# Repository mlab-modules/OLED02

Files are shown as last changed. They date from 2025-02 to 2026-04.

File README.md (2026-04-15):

# OLED02 Display with I2C interface

The **OLED02A** is a simplified variant of the MLAB [OLED01](https://github.com/mlab-modules/OLED01) module. It features a 1.3-inch blue OLED display using the SSD1306BZ controller and communicates over an I²C interface.

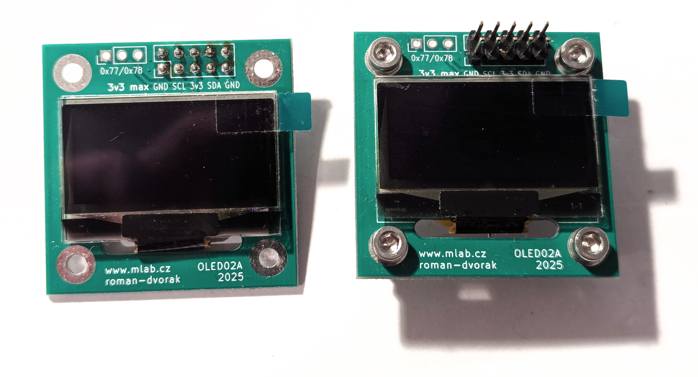
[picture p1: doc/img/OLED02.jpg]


## Features
- **Display**: 1.3-inch passive matrix OLED with a resolution of 128x64 pixels.
- **Color**: Blue.
- **Controller**: SSD1306BZ.
- **Interface**: I²C.
- **Power Supply**:
  - Logic: 3.0 V typical (2.8 V min, 3.3 V max).
  - Display: Internally generated by integrated DC/DC converter.
- **Address Configuration**: Default I²C address is `0x3C`, changeable to `0x3D` via onboard jumper.
- **Mounting**:
  - Horizontal MLAB standard.
  - Optional vertical placement using a 3D-printed holder.

## Electrical Characteristics

- **Operating Voltage (Logic)**: 2.8 V to 3.3 V
- **Operating Current**: \~10 mA @ 12 V VCC (internally generated)
- **Interface Voltage Levels**: TTL-compatible (0 to 3.3 V)

## Optical Characteristics

- **Contrast Ratio**: 2000:1
- **Brightness**: 60–80 cd/m² (typical with 50% checkboard)
- **Viewing Angle**: 160° (H and V)
- **Response Time**: 10 µs (rise and fall)
- **Display Technology**: Passive matrix
- **Pixel Size**: 0.148 mm x 0.148 mm
- **Dot Pitch**: 0.17 mm x 0.17 mm
- **Active Area**: 21.738 mm x 10.858 mm

## Mechanical Parameters

- **Board Dimensions**: 40.14 mm x 40.14 mm
- **Board Thickness**: 1.6 mm
- **Mounting**: Compatible with standard MLAB module placement

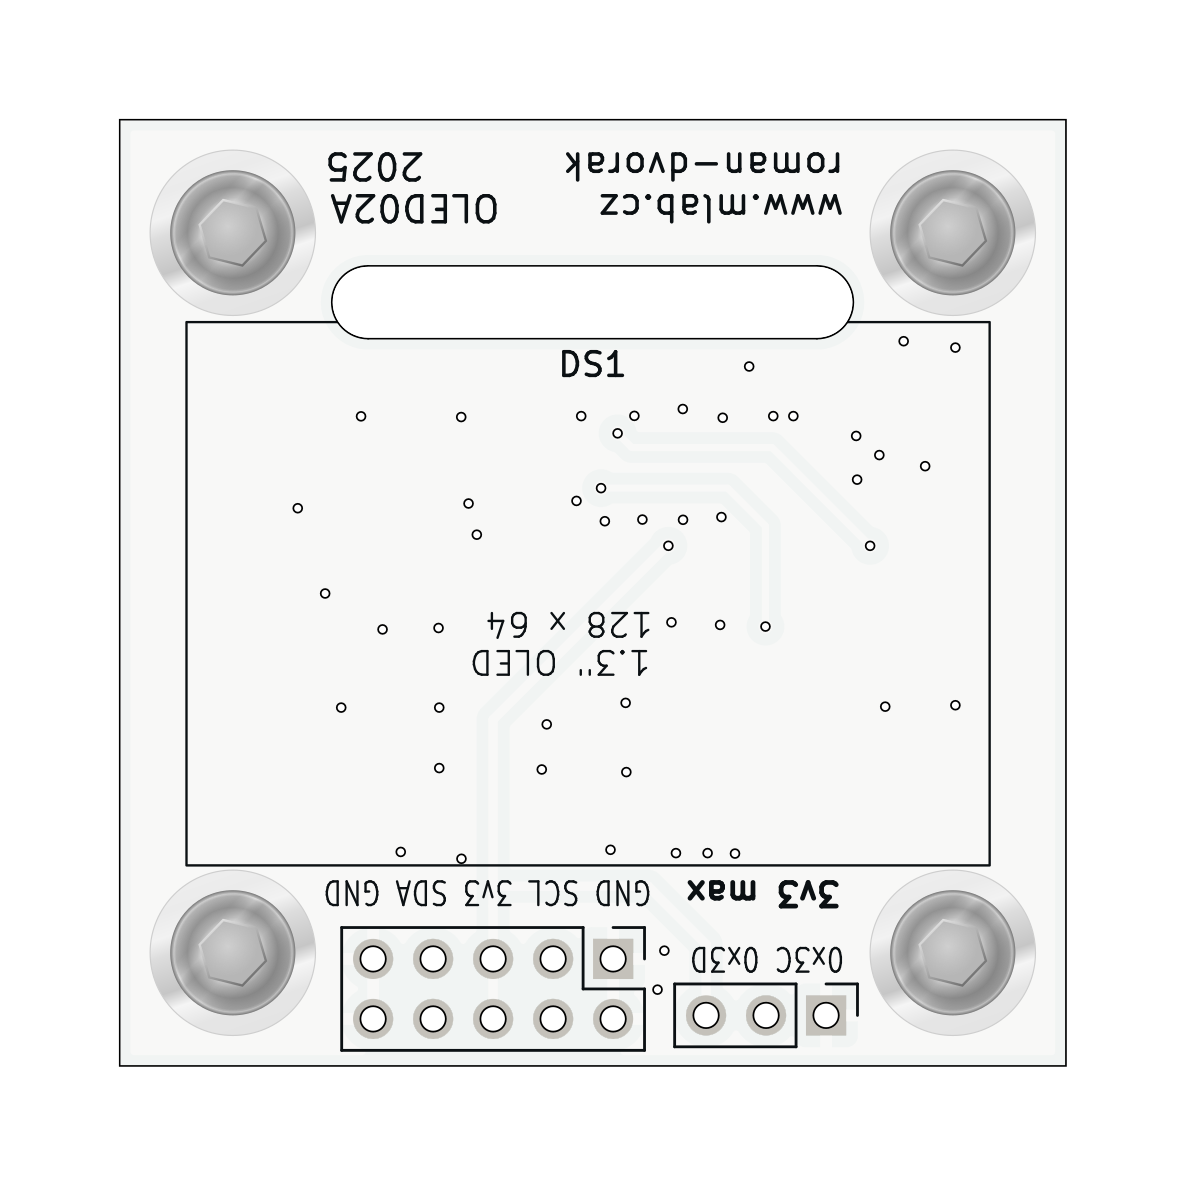
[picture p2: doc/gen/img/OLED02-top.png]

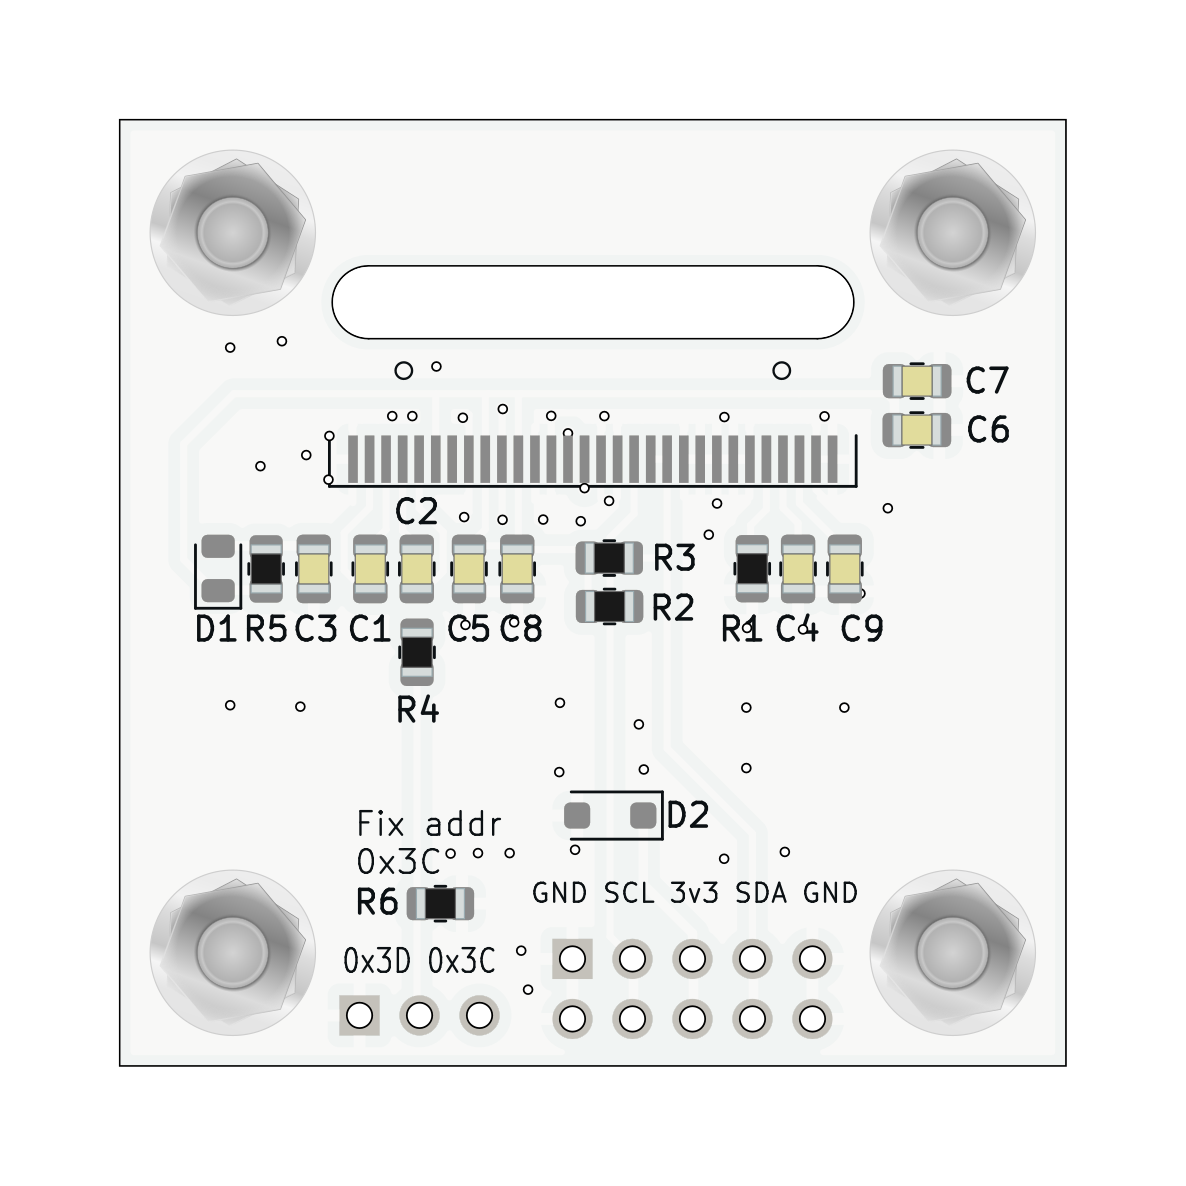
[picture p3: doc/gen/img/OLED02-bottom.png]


## I²C Pin Configuration (Standard MLAB I2C Layout)

| Pin | Name | Description |
| --- | ---- | --- |
| 1 | GND  | Ground |
| 2 | SDA  | Serial Data |
| 3 | 3V3  | 3.3V power supply |
| 4 | SCL  | Serial Clock |
| 5 | GND  | Ground |

## I²C Address Selection

The OLED02A module uses `0x3C` as its default I²C address. By bridging the onboard address jumper, the address switches to `0x3D`.

## Notes

- OLED02A omits certain advanced features present in OLED01 to simplify integration and reduce cost.
- The module uses only the I²C interface; SPI and parallel interfaces supported by the SSD1306BZ are not routed.
- Ensure proper handling precautions for OLEDs to prevent damage or screen burn-in.
- Refer to the [SSD1306 datasheet](https://www.vishay.com/doc?37902) for command interface details.

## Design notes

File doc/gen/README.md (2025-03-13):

# PCB

Board size: 40.14x40.14 mm (1.58x1.58 inches)

- This is the size of the rectangle that contains the board
- Thickness: 1.6 mm (63 mils)
- Material: FR4
- Finish: HAL
- Layers: 2
- Copper thickness: 35 µm

Solder mask: TOP / BOTTOM

- Color: Green

Silk screen: TOP / BOTTOM

- Color: White

# Important sizes

Clearance: 0.2 mm (8 mils)

Track width: 0.3 mm (12 mils)

- By design rules: 0.0 mm (0 mils)

Drill: 0.4 mm (16 mils)

- Vias: 0.4 mm (16 mils) [Design: 0.4 mm (16 mils)]
- Pads: 1.1 mm (43 mils)
- The above values are real drill sizes, they add 0.1 mm (4 mils) to plated holes (PTH)

Via: 0.6/0.3 mm (24/12 mils)

- By design rules: 0.5/0.3 mm (20/12 mils)
- Micro via: yes [0.2/0.1 mm (8/4 mils)]
- Buried/blind via: yes
- Total: 50 (thru: 50 buried/blind: 0 micro: 0)

Outer Annular Ring: 0.1 mm (4 mils)

- By design rules: 0.3 mm (12 mils)

Eurocircuits class: 6C
- Using min drill 0.35 mm for an OAR of 0.13 mm

# General stats

Components count: (SMD/THT)

- Top: 0/6 (THT)
- Bottom: 18/0 (SMD)

Defined tracks:

- 0.2 mm (8 mils)
- 0.3 mm (12 mils)
- 0.4 mm (16 mils)

Used tracks:

- 0.3 mm (12 mils) (94) defined: yes
- 0.4 mm (16 mils) (21) defined: yes

Defined vias:

Used vias:

- 0.6/0.3 mm (24/12 mils) (Count: 50, Aspect: 2.7 A) defined: no

Holes (excluding vias):

- 1.0 mm (39 mils) (13)
- 3.0 mm (118 mils) (4)

Oval holes:

Drill tools (including vias and computing adjusts and rounding):

- 0.4 mm (16 mils) (50)
- 1.1 mm (43 mils) (13)
- 3.1 mm (122 mils) (4)

Solder paste stats:

Using a paste with 87.75 % alloy, that has an specific gravity for the alloy of 7.4 g/cm³
and 1.0 g/cm³ for the flux. This paste has an specific gravity of  4.15 g/cm³.

The stencil thickness is  0.12 mm.

| Side | Pads with paste | Area [mm²] | Paste [g] |
|---|---|---|---|
| Total  | 64 | 70.48 | 0.35 |

Note: this is just an approximation to the theoretical value. Margins of the solder mask and waste aren't computed.

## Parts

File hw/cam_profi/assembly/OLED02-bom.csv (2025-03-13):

Component | Description | Part | References | Value | Footprint | Quantity Per PCB | Datasheet | sim.device | sim.pins | ust_id
1 | Unpolarized capacitor, small symbol | C_Small | C5C6 | 100n | C_0805_2012Metric | 2 | ~
2 | Unpolarized capacitor, small symbol | C_Small | C1C2 | 1u | C_0805_2012Metric | 2 | ~
3 | Unpolarized capacitor, small symbol | C_Small | C4C9 | 4u7 | C_0805_2012Metric | 2 | ~
4 | Unpolarized capacitor, small symbol | C_Small | C3C7C8 | 10u | C_0805_2012Metric | 3 | ~
5 | Diode, small symbol | D_Small | D1 | 1N4148 | D_0805_2012Metric | 1 | ~ | D | 1=K 2=A
6 | Zener diode | D_Zener | D2 | BZT52H-C3V6,115 | D_SOD-123F | 1 | ~ |  |  | 650b35ab462c6d9e720543d0
7 | OLED display 128x64 | OLED-128O064D | DS1 | OLED-128O064D | OLED-128O064D | 1 | https://www.vishay.com/docs/37902/oled128o064dbpp3n00000.pdf
8 | 2x05 2.54 mm pitch header, 2 pins next to each other are connected | HEADER_2x05_PARALLEL | J2 | HEADER_2x05_PARALLEL | PinHeader_2x05_P2.54mm_Vertical | 1
9 | Resistor, small symbol | R_Small | R4 | 100R | R_0805_2012Metric | 1 | ~
10 | Resistor, small symbol | R_Small | R2R3R5R6 | 4k7 | R_0805_2012Metric | 4 | ~
11 | Resistor, small symbol | R_Small | R1 | 560k | R_0805_2012Metric | 1 | ~

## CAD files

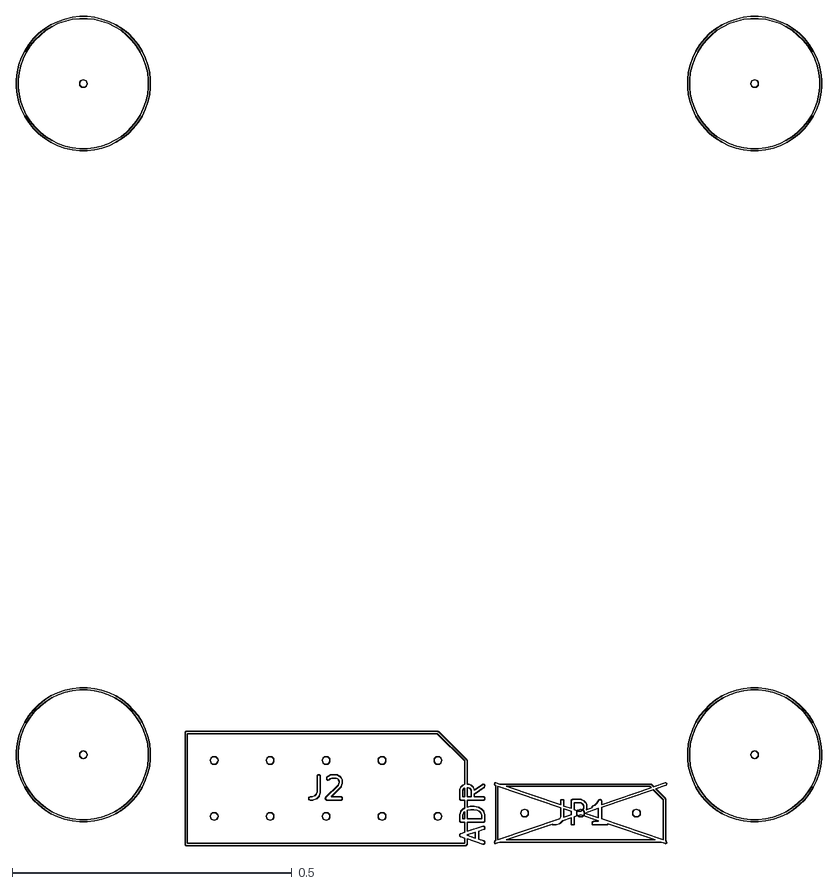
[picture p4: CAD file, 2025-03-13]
doc/gen/dxf/OLED02-F_Fab.dxf
1.44 x 1.48

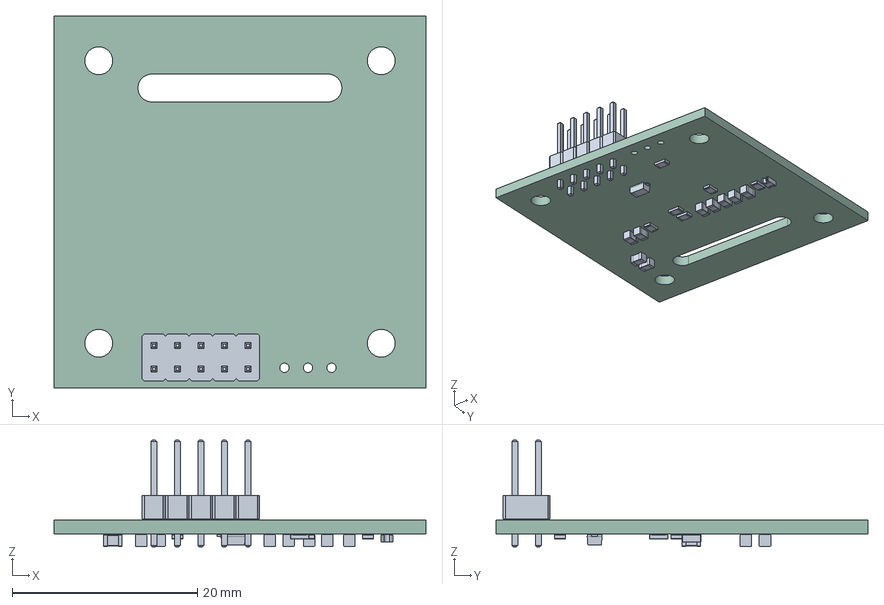
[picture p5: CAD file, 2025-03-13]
doc/gen/OLED02.step
40.1 x 40.1 x 11.5 mm
PinHeader_2x05_P2.54mm_Vertical
D_0805_2012Metric
C_0805_2012Metric x 9
R_0805_2012Metric x 6
D_SOD-123F
kibot_b_ytgxez_PCB

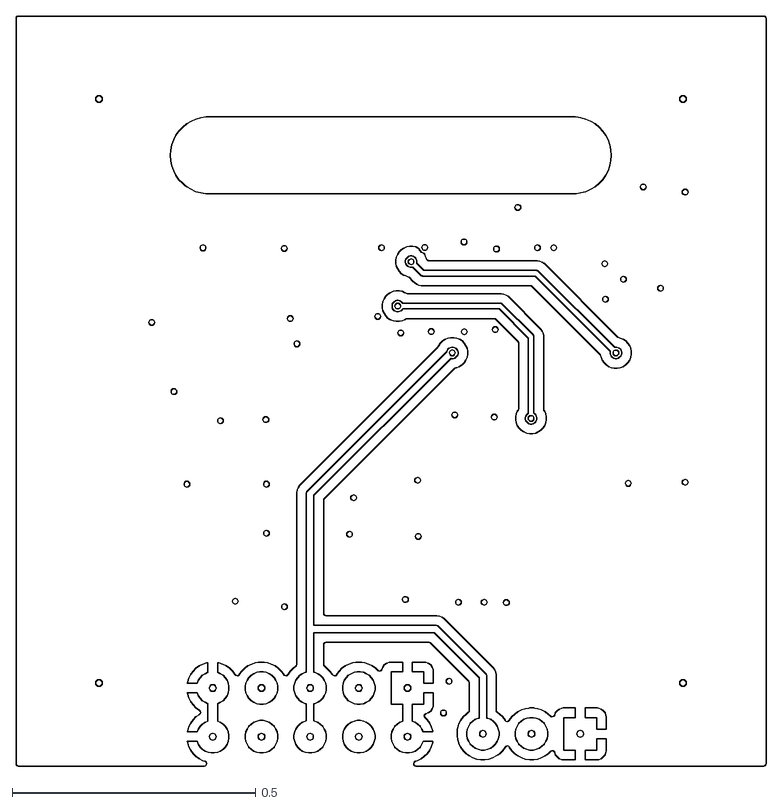
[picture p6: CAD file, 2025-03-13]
doc/gen/dxf/OLED02-F_Cu.dxf
1.54 x 1.54

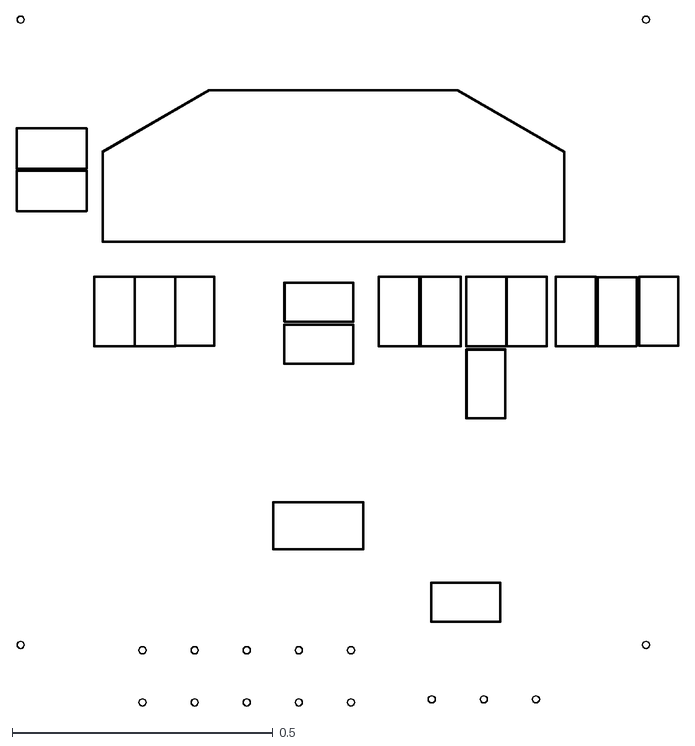
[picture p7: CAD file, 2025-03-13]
doc/gen/dxf/OLED02-B_Courtyard.dxf
1.27 x 1.32

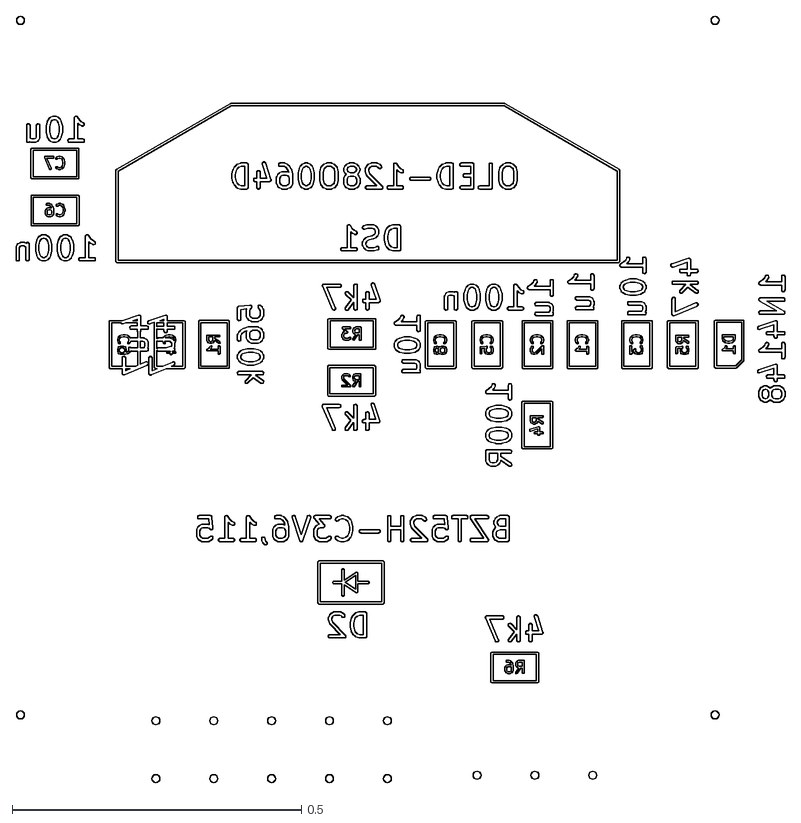
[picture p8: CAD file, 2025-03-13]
doc/gen/dxf/OLED02-B_Fab.dxf
1.33 x 1.32

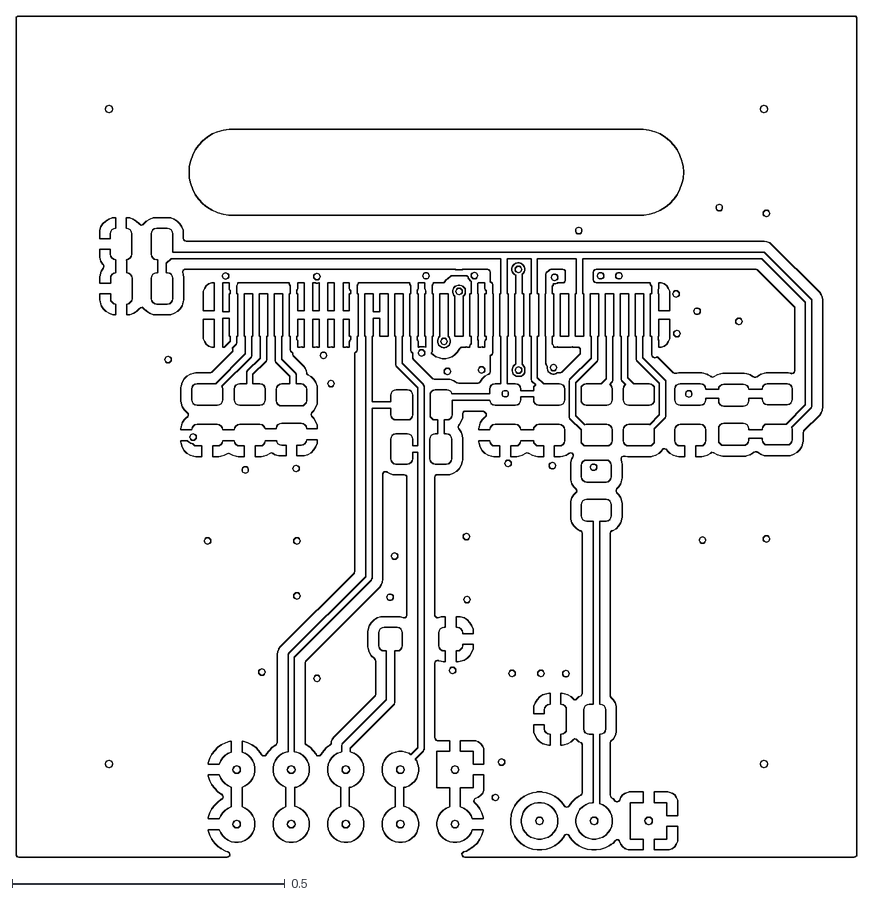
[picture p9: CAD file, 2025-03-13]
doc/gen/dxf/OLED02-B_Cu.dxf
1.54 x 1.54

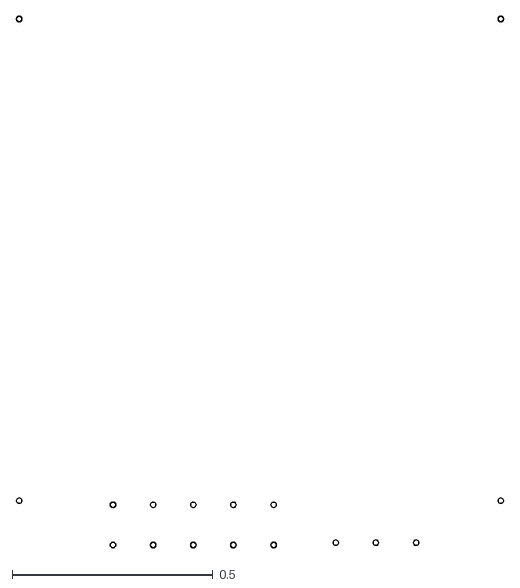
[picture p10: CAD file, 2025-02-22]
doc/gen/dxf/OLED02-User_3.dxf
1.21 x 1.32

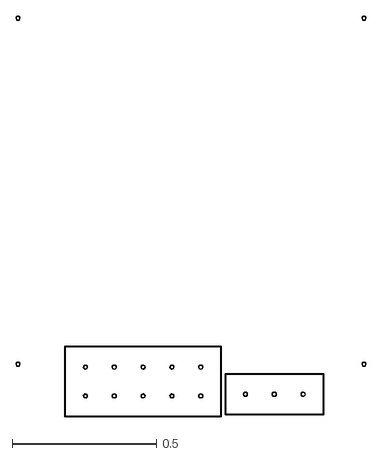
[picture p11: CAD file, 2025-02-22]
doc/gen/dxf/OLED02-F_Courtyard.dxf
1.21 x 1.39

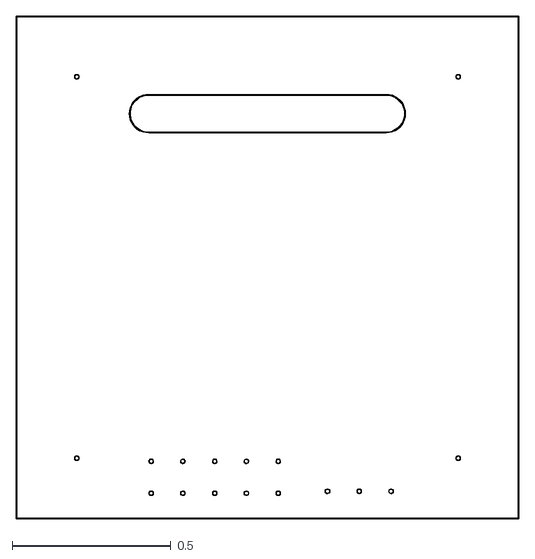
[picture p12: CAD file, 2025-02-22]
doc/gen/dxf/OLED02-Edge_Cuts.dxf
1.58 x 1.58

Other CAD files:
doc/gen/dxf/OLED02-B_Adhesive.dxf
doc/gen/dxf/OLED02-B_Mask.dxf
doc/gen/dxf/OLED02-B_Paste.dxf
doc/gen/dxf/OLED02-B_Silkscreen.dxf
doc/gen/dxf/OLED02-F_Adhesive.dxf
doc/gen/dxf/OLED02-F_Mask.dxf
doc/gen/dxf/OLED02-F_Paste.dxf
doc/gen/dxf/OLED02-F_Silkscreen.dxf

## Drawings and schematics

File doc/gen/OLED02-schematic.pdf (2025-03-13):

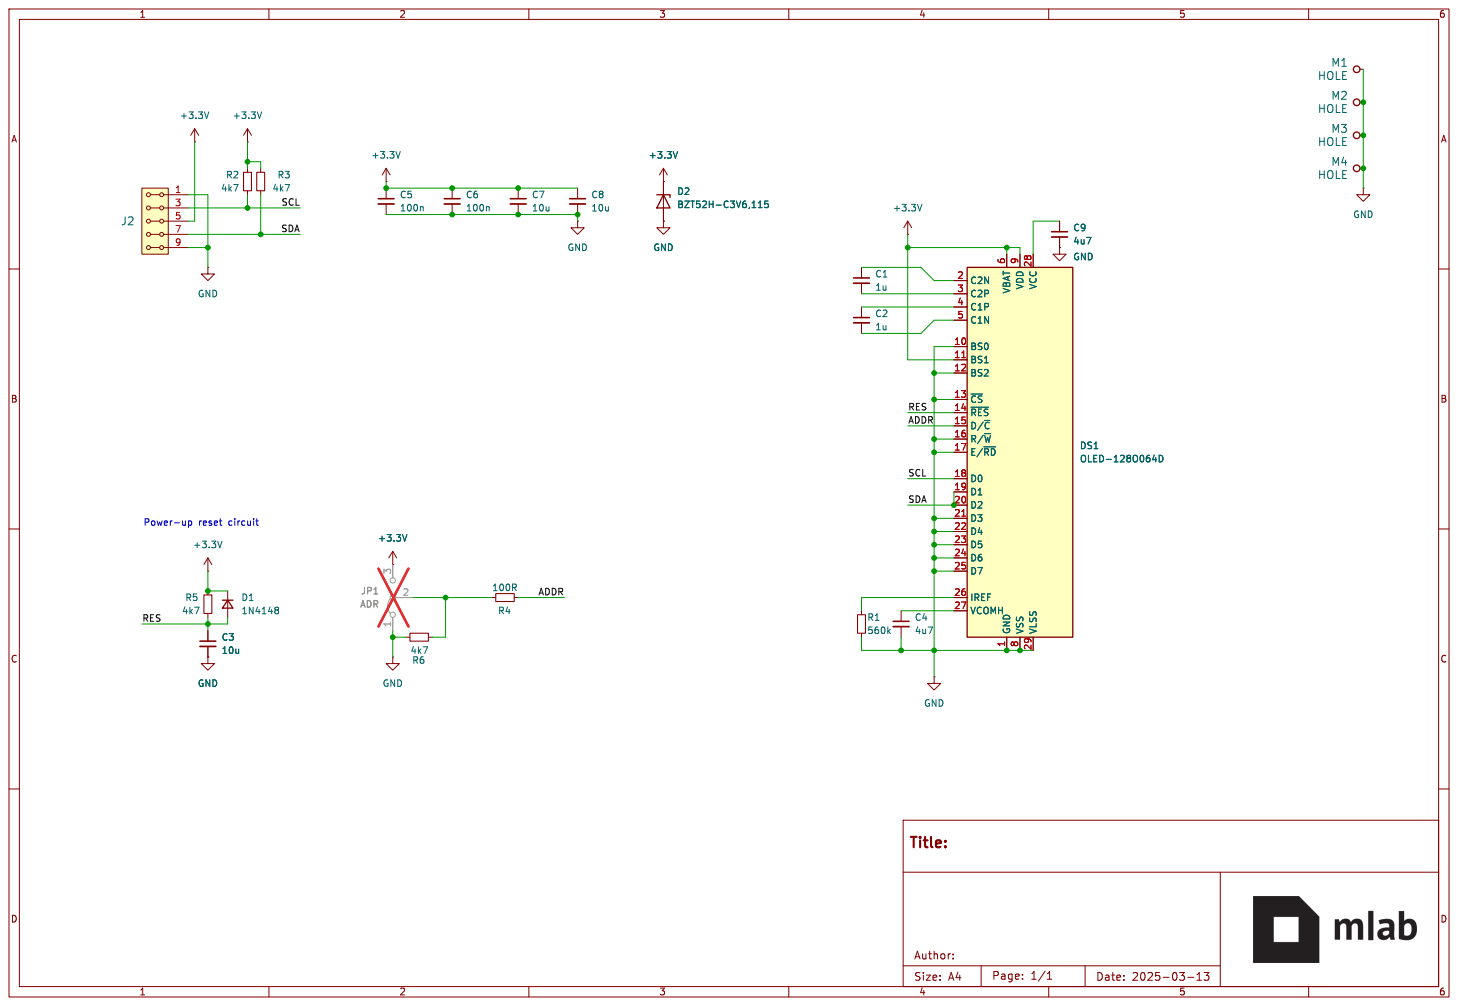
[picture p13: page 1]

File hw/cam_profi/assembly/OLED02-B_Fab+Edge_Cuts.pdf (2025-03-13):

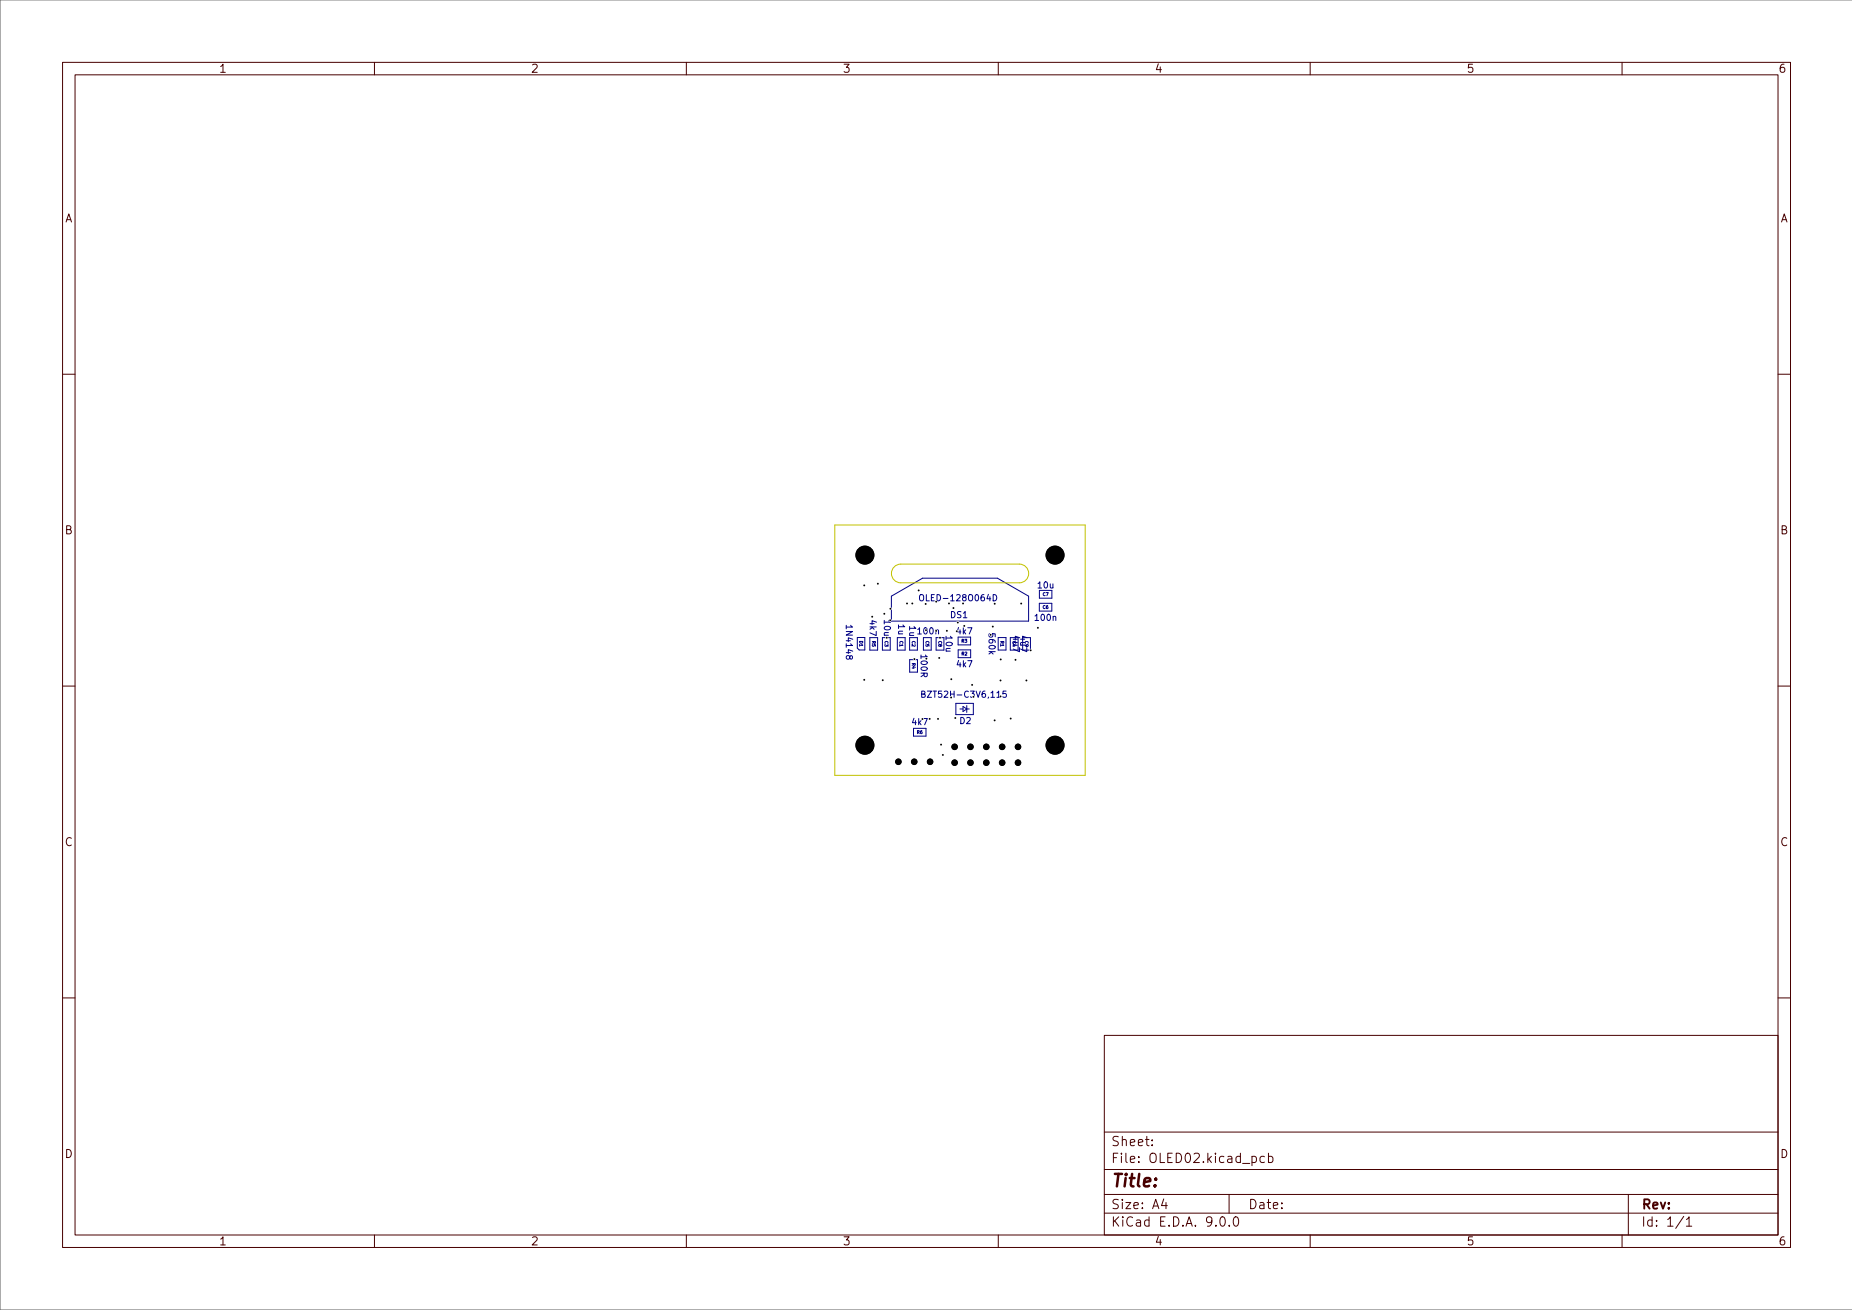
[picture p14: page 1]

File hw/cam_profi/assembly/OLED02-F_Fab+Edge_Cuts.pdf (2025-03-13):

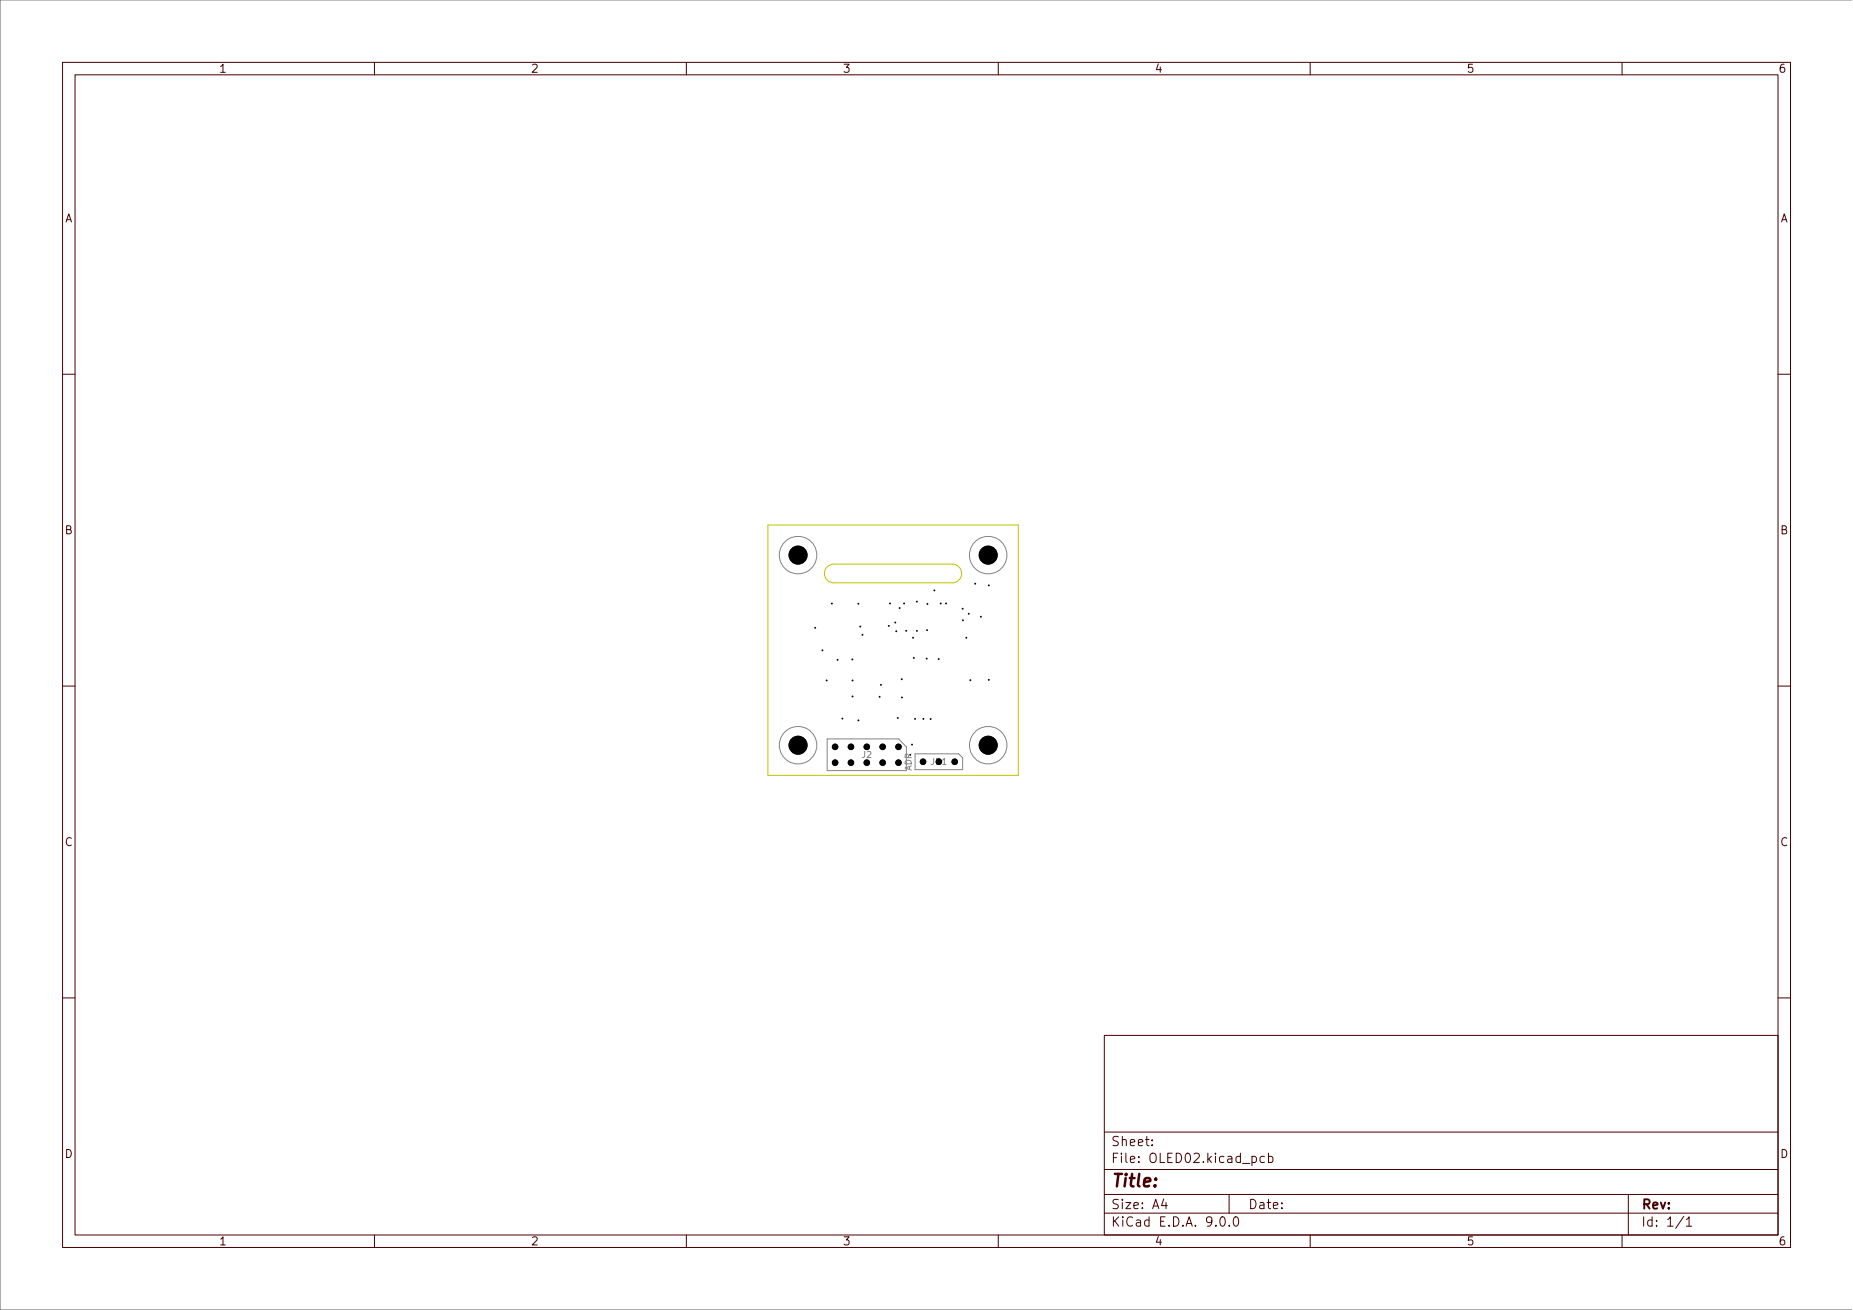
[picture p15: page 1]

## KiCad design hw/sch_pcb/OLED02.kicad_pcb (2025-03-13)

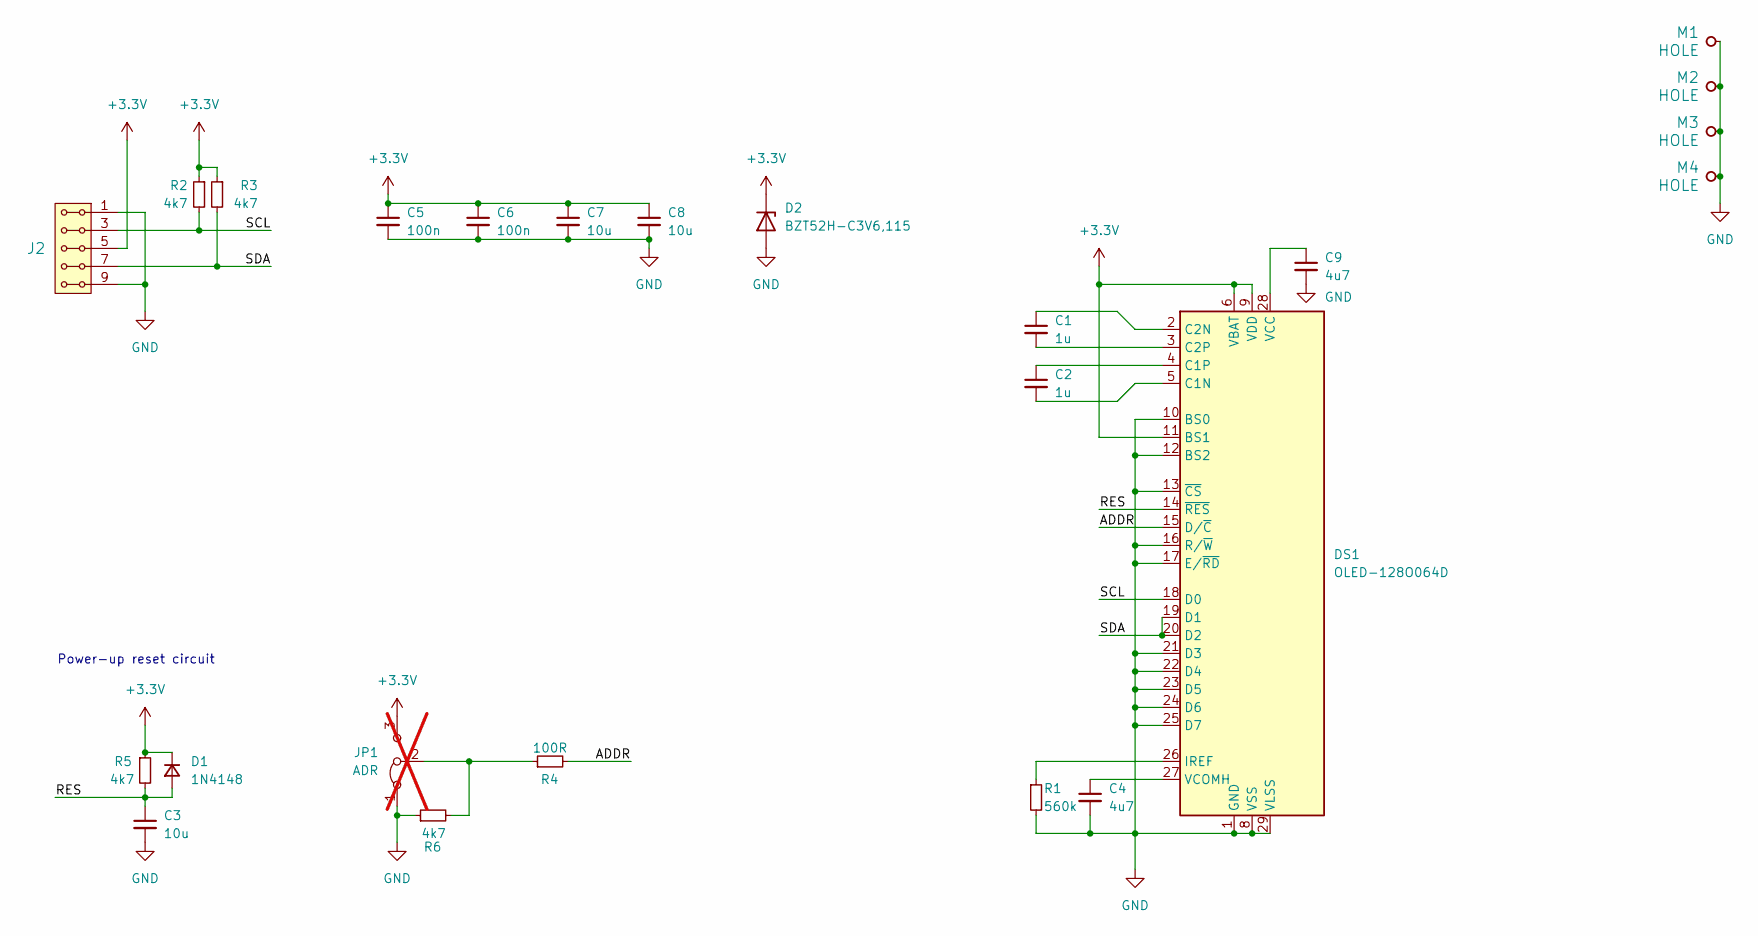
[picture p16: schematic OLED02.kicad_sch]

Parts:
C1, C2: 1u; C_0805_2012Metric
C3, C7, C8: 10u; C_0805_2012Metric
C4, C9: 4u7; C_0805_2012Metric
C5, C6: 100n; C_0805_2012Metric
D1: 1N4148; D_0805_2012Metric
D2: BZT52H-C3V6,115; D_SOD-123F
DS1: OLED-128O064D
J2: HEADER_2x05_PARALLEL; PinHeader_2x05_P2.54mm_Vertical
JP1: ADR; PinHeader_1x03_P2.54mm_Vertical; not fitted
M1, M2, M3, M4: HOLE; MountingHole_3mm
R1: 560k; R_0805_2012Metric
R2, R3, R5, R6: 4k7; R_0805_2012Metric
R4: 100R; R_0805_2012Metric

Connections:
+3.3V: C5.1, C6.1, C7.1, C8.1, D1.1 (K), D2.1 (K), DS1.6 (VBAT), DS1.9 (VDD), DS1.11 (BS1), J2.5, J2.6, JP1.3 (B), R2.1, R3.1, R5.1
/ADDR: DS1.15 (D/~C), R4.2
/RES: C3.1, D1.2 (A), DS1.14 (~RES), R5.2
/SCL: DS1.18 (D0), J2.3, J2.4, R2.2
/SDA: DS1.19 (D1), DS1.20 (D2), J2.7, J2.8, R3.2
GND: C3.2, C4.2, C5.2, C6.2, C7.2, C8.2, C9.2, D2.2 (A), DS1.1 (GND), DS1.8 (VSS), DS1.10 (BS0), DS1.12 (BS2), DS1.13 (~CS), DS1.16 (R/~W), DS1.17 (E/~RD), DS1.21 (D3), DS1.22 (D4), DS1.23 (D5), DS1.24 (D6), DS1.25 (D7), DS1.29 (VLSS), DS1.30 (GND), J2.1, J2.2, J2.9, J2.10, JP1.1 (A), M1.1, M2.1, M3.1, M4.1, R1.2, R6.1
unnamed: C2.2, DS1.5 (C1N)
unnamed: C2.1, DS1.4 (C1P)
unnamed: C1.1, DS1.2 (C2N)
unnamed: C1.2, DS1.3 (C2P)
unnamed: DS1.26 (IREF), R1.1
unnamed: C9.1, DS1.28 (VCC)
unnamed: C4.1, DS1.27 (VCOMH)
unnamed: JP1.2 (C), R4.1, R6.2

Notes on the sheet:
Power-up reset circuit

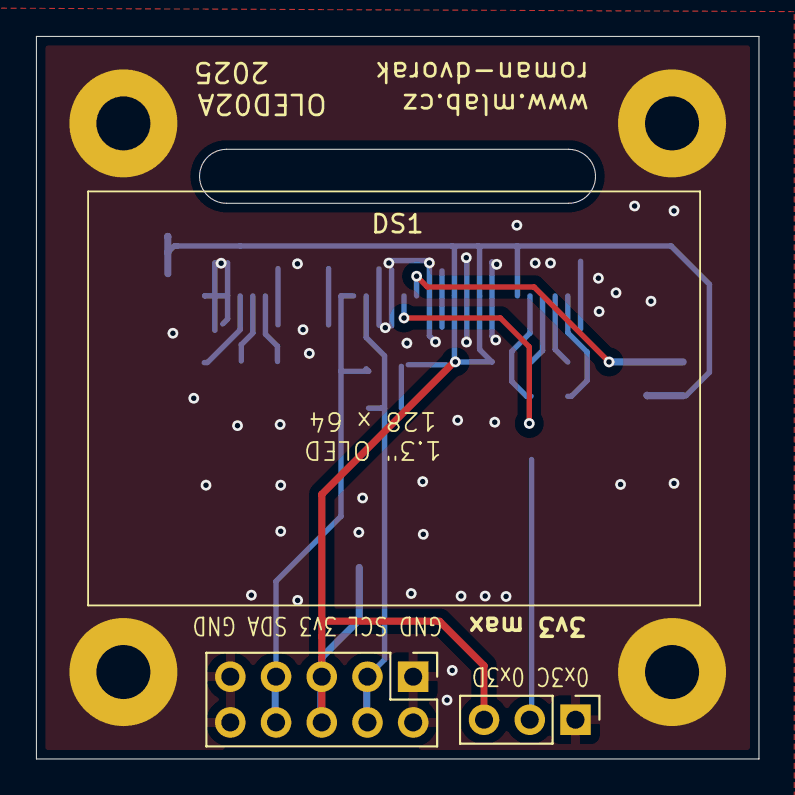
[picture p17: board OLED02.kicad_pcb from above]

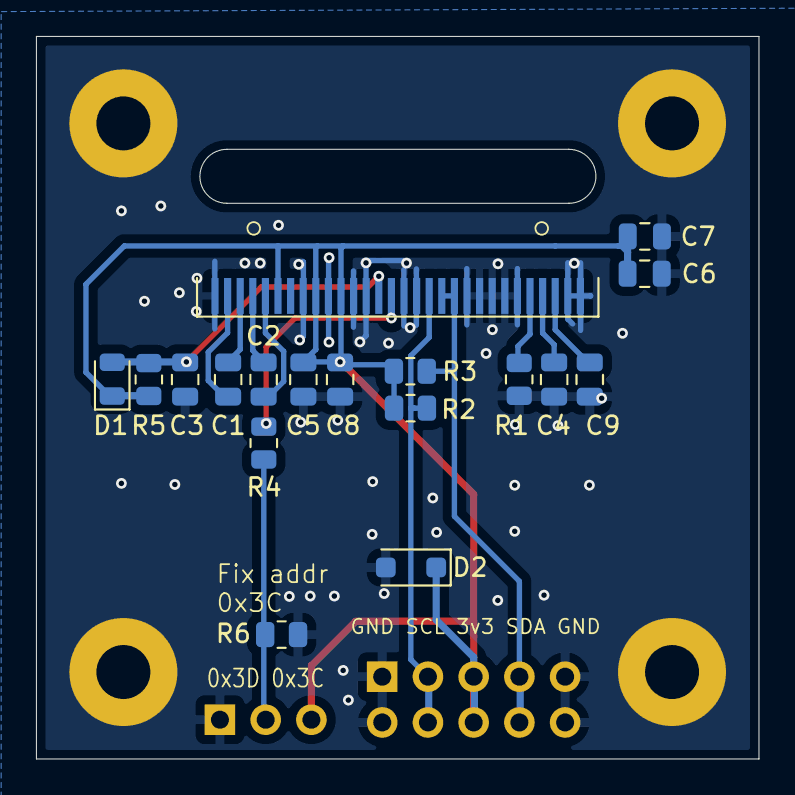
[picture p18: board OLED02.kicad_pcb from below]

Board: 2 copper layers, 40.1 x 40.1 mm, 24 parts (18 on the bottom side), 14 nets.

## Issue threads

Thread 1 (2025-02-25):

Upside down renders

kaklik, 2025-02-25:
Modul je nakreslený tak, že má popisky hlavou dolů.

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

V další revizi by se ho hodilo otočit tak, aby popisky byly normálně čitelné při standardní orientaci obrázků na webu.

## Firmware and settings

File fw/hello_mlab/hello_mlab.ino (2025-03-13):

#include <Wire.h>
#include <U8g2lib.h>

#define LED_PIN 25

// Konstruktor pro SH1106 128x64 (hardwarové I2C)
// Používáme orientaci U8G2_R0, reset pin nepoužíváme (U8X8_PIN_NONE)
U8G2_SH1106_128X64_NONAME_F_HW_I2C u8g2(U8G2_R0, /* reset=*/ U8X8_PIN_NONE);


// Bitmapa loga MLAB (40x26 pixelů), přesný binární zápis bez prvního prázdného sloupce
const unsigned char mlab_logo_bits[] PROGMEM = {
  0b11111111, 0b11111111, 0b00000000,
  0b11111111, 0b11111111, 0b00000001,
  0b11111111, 0b11111111, 0b00000011,
  0b11111111, 0b11111111, 0b00000111,
  0b11111111, 0b11111111, 0b00001111,
  0b11111111, 0b11111111, 0b00011111,
  0b11111111, 0b11111111, 0b00111111,
  0b11111111, 0b11111111, 0b01111111,
  0b11111111, 0b00000000, 0b11111111,
  0b11111111, 0b00000000, 0b11111111,
  0b11111111, 0b00000000, 0b11111111,
  0b11111111, 0b00000000, 0b11111111,
  0b11111111, 0b00000000, 0b11111111,
  0b11111111, 0b00000000, 0b11111111,
  0b11111111, 0b00000000, 0b11111111,
  0b11111111, 0b00000000, 0b11111111,
  0b11111111, 0b11111111, 0b11111111,
  0b11111111, 0b11111111, 0b11111111,
  0b11111111, 0b11111111, 0b11111111,
  0b11111111, 0b11111111, 0b11111111,
  0b11111111, 0b11111111, 0b11111111,
  0b11111111, 0b11111111, 0b11111111,
  0b11111111, 0b11111111, 0b11111111,
  0b11111111, 0b11111111, 0b11111111
};

// Funkce vykreslí bitmapu do středu displeje
void drawMLABLogoCentered() {
  int logo_width = 24;
  int logo_height = 25;

  int x = (128 - logo_width) / 2; // Střed displeje (šířka 128 px)
  int y = (64 - logo_height) / 2; // Střed displeje (výška 64 px)

  u8g2.drawXBMP(x, y, logo_width, logo_height, mlab_logo_bits);
}




void setup() {
  // Nastavení I2C pinů pro Raspberry Pi Pico
  Wire.setSDA(12);
  Wire.setSCL(13);
  Wire.begin();

  // Inicializace OLED displeje
  u8g2.begin();
  
  // Zobrazení textu na displeji
  u8g2.firstPage();
  do {
    u8g2.setFont(u8g2_font_ncenB08_tr);
    u8g2.drawStr(0, 8, "Ahoj!   OLED02A");
    // u8g2.drawStr(0, 25, "OLED02A");
    u8g2.drawStr(0, 64, "MLAB.cz");

    drawMLABLogoCentered();


  } while (u8g2.nextPage());

  // Nastavení LED pinu jako výstup
  pinMode(LED_PIN, OUTPUT);
}

void loop() {
  // Blikání vestavěné LED (pin 25) s periodou 500 ms
  digitalWrite(LED_PIN, HIGH);
  delay(500);
  digitalWrite(LED_PIN, LOW);
  delay(500);
}

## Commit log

2025-02-22 initial version
    [OLED02.kicad_pcb, OLED02.kicad_sch]
2025-02-22 rename folder
    [OLED02.kicad_pcb, OLED02.kicad_sch]
2025-02-22 Update actions products
    [OLED02-B_Adhesive.dxf, OLED02-B_Courtyard.dxf, OLED02-B_Cu.dxf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]
2025-02-25 Update status and fab Layer.
    [OLED02.kicad_pcb, OLED02.kicad_sch]
2025-03-13 update kicad version
    [OLED02.kicad_pcb, OLED02.kicad_sch]
